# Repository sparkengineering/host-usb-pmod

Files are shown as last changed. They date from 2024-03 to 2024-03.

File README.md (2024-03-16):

# host-usb-pmod




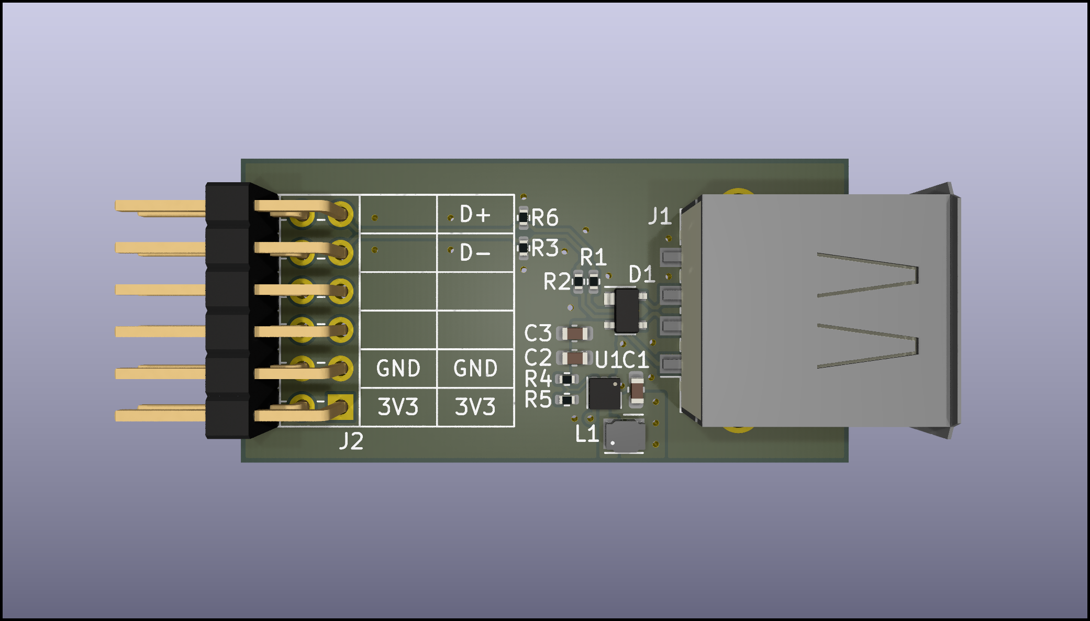
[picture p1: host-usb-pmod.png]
3D render of this USB Pmod breakout board


## Description

USB type A receptacle to Digilent Pmod™ breakout board.

- Impedance matched & length tuned differential lines
- Includes 3.3V to 5V boost converter (max. 800mA)
- Pinout to match Digilent high-speed Pmod™ e.g. on Arty A7
- Tested with Arty A7 board and USB 1.0 LS HID devices

## Contents

| File | Description |
|---|---|
| [host-usb-pmod.pdf](./host-usb-pmod.pdf) | Schematic in PDF format |
| [host-usb-pmod.csv](./host-usb-pmod.csv) | BOM in CSV format |
| [host-usb-pmod.png](./host-usb-pmod.png) | PCB 3D render |
| | |
| [host-usb-pmod.kicad_pro](./host-usb-pmod.kicad_pro) | KiCad 8.0.0 project |
| [host-usb-pmod.kicad_pcb](./host-usb-pmod.kicad_pcb) | KiCad 8.0.0 PCB |
| [host-usb-pmod.kicad_sch](./host-usb-pmod.kicad_sch) | KiCad 8.0.0 schematic |

## Further Reading

- Ben Eater: How does a USB keyboard work? [^1]
- Compact USB HID host FPGA core [^2]
- A dual-socket USB host PMOD module [^3]
- Universal Serial Bus Specification 1.0 [^4]
- USB Host Dual Socket Pmod™ Compatible Module [^5]

[^1]: https://www.youtube.com/watch?v=wdgULBpRoXk
[^2]: https://github.com/nand2mario/usb_hid_host
[^3]: https://github.com/nand2mario/usb_host_pmod
[^4]: https://fabiensanglard.net/usbcheat/usb1.pdf
[^5]: https://machdyne.com/product/usb-host-dual-socket-pmod/

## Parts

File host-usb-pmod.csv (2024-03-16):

Reference | Value | Footprint | Qty | DNP | MFG | MPN | OC_LCSC | OC_Mouser
C1,C2,C3 | 10µF | Capacitor_SMD:C_0603_1608Metric | 3 |  | Murata Electronics | GRM188Z71A106KA73D | C2959727 | 81-GRM188Z71A106KA3D
D1 | SP0503BAHT | Package_TO_SOT_SMD:SOT-143 | 1 |  | Littelfuse | SP0503BAHTG | C7074 | 576-SP0503BAHTG
J1 | USB_A | host-usb-pmod:USB_A_TE_292303-7_Horizontal | 1 |  | TE Connectivity | 292303-7 | ~ | 571-292303-7
J2 | Conn_02x06_Odd_Even | host-usb-pmod:PinHeader_2x06_P2.54mm_Horizontal | 1 |  | TE Connectivity | 826634-6 | ~ | 571-826634-6
L1 | 2.2µH | Inductor_SMD_Wurth:L_Wurth_WE-LQSH-2512 | 1 |  | Wurth Elektronik | 74404024022 | ~ | 710-74404024022
R1,R2 | 22Ω | Resistor_SMD:R_0402_1005Metric | 2 |  | YAGEO | RC0402FR-0722RL | C114765 | 603-RC0402FR-0722RL
R3,R6 | 15kΩ | Resistor_SMD:R_0402_1005Metric | 2 |  | YAGEO | RC0402FR-0715KL | C114761 | 603-RC0402FR-0715KL
R4 | 1MΩ | Resistor_SMD:R_0402_1005Metric | 1 |  | YAGEO | RC0402FR-071ML | C138033 | 603-RC0402FR-071ML
R5 | 249kΩ | Resistor_SMD:R_0402_1005Metric | 1 |  | YAGEO | RC0402FR-07249KL | C163476 | 603-RC0402FR-07249KL
U1 | TPS61099DRV | Package_SON:WSON-6-1EP_2x2mm_P0.65mm_EP1x1.6mm | 1 |  | Texas Instruments | TPS61099DRVR | C2842395 | 595-TPS61099DRVR

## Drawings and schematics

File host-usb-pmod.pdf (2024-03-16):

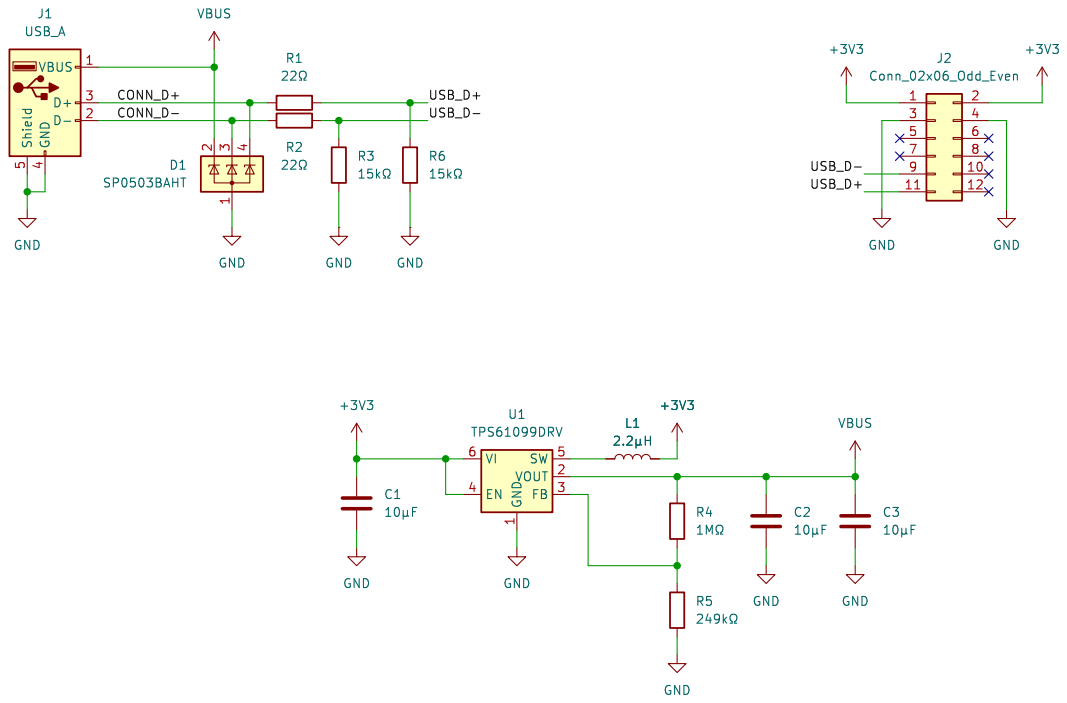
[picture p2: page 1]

1 VOUT 2 FB 3 EN 4 SW 5 VI 6 U1 TPS61099DRV

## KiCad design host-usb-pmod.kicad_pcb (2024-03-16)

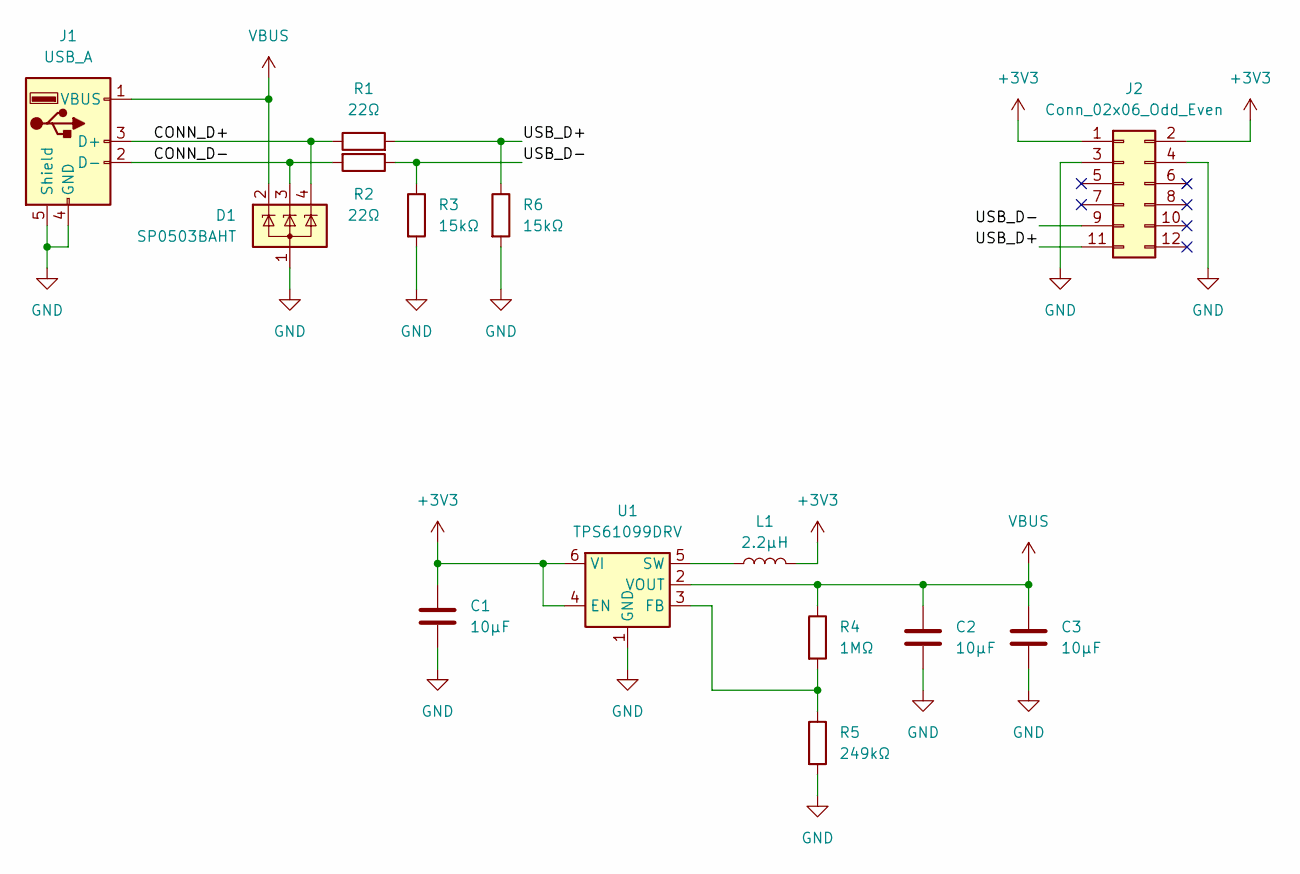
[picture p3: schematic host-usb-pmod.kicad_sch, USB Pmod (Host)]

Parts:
C1, C2, C3: 10µF; C_0603_1608Metric; MPN GRM188Z71A106KA73D
D1: SP0503BAHT; SOT-143; MPN SP0503BAHTG
J1: USB_A; USB_A_TE_292303-7_Horizontal; MPN 292303-7
J2: Conn_02x06_Odd_Even; PinHeader_2x06_P2.54mm_Horizontal; MPN 826634-6
L1: 2.2µH; L_Wurth_WE-LQSH-2512; MPN 74404024022
R1, R2: 22Ω; R_0402_1005Metric; MPN RC0402FR-0722RL
R3, R6: 15kΩ; R_0402_1005Metric; MPN RC0402FR-0715KL
R4: 1MΩ; R_0402_1005Metric; MPN RC0402FR-071ML
R5: 249kΩ; R_0402_1005Metric; MPN RC0402FR-07249KL
U1: TPS61099DRV; WSON-6-1EP_2x2mm_P0.65mm_EP1x1.6mm; MPN TPS61099DRVR

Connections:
+3V3: C1.1, J2.1, J2.2, L1.2, U1.4 (EN), U1.6 (VI)
/CONN_D+: D1.4 (K), J1.3 (D+), R1.1
/CONN_D-: D1.3 (K), J1.2 (D-), R2.2
/USB_D+: J2.11, R1.2, R6.1
/USB_D-: J2.9, R2.1, R3.1
GND: C1.2, C2.2, C3.2, D1.1 (A), J1.4 (GND), J1.5 (Shield), J2.3, J2.4, R3.2, R5.2, R6.2, U1.1 (GND), U1.7 (GND)
unnamed: R4.2, R5.1, U1.3 (FB)
unnamed: L1.1, U1.5 (SW)
VBUS: C2.1, C3.1, D1.2 (K), J1.1 (VBUS), R4.1, U1.2 (VOUT)

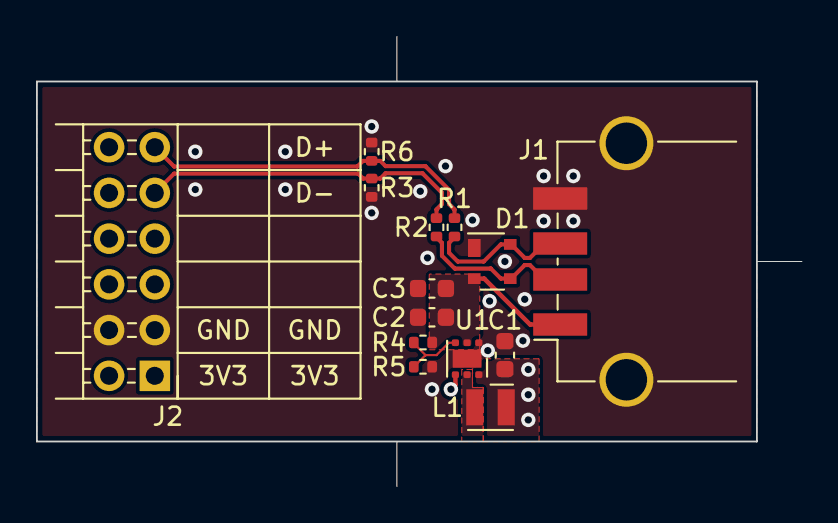
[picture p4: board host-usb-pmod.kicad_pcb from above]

Board: 4 copper layers, 40.0 x 20.0 mm, 14 parts (0 on the bottom side), 9 nets.
